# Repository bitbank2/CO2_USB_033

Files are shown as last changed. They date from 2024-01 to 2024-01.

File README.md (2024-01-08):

CO2_USB_033
===========
<b>What is it?</b><br>
A KiCad PCB project plus firmware for a portable CO2 sensor based on the WCH CH32X033 MCU. This is my first PCB with this chip and so far it's impressing me quite a bit. I was able to buy a small quantity for about 23 cents each. The 033 is part of the CH32X035 family and has a 48Mhz RISC-V core with 20K SRAM, 62K FLASH, USB full speed and many of the typical I/O capabilities of 32-bit MCUs. This project was more of an experiment to see if I could easily add some USB functionality to my battery powered CO2 sensor.<br><br>
<b>What's special about this project?</b><br>
By using a low cost display, MCU and sensor, my aim for this project was to make a practical and low cost way to carry a true CO2 sensor in your pocket. The CH32X033 also allowed me to easily add USB CDC support so that a PC could receive the sensor readings too. I use a clever single pushbutton circuit to control power and input. By using the enable pin of the 3.3v regulator in software control, the device can turn itself off. I use this feature to make sure the battery isn't accidentally left for dead. After 5 minutes of use, it will turn itself off.<br><br>
<b>Building the Project</b><br>
I used KiCad to design the PCB and all of the source files and Gerber zip is in the PCB folder ready to send for production. I assembled the board myself, so I don't have any assembly instructions/files with it. The firmware was built using MounRiver Studio IDE and the CH32X035 EVT provided on the WCH website.<br>

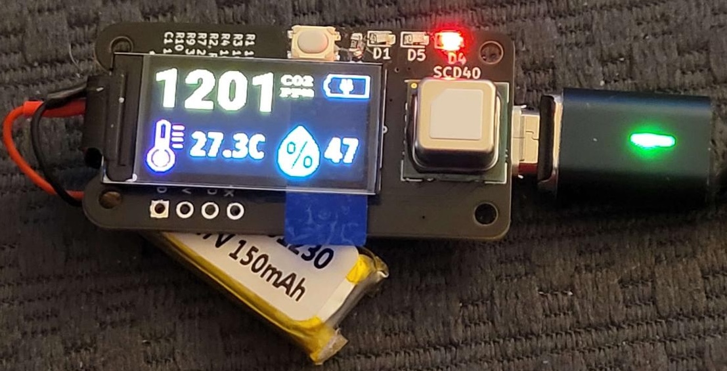
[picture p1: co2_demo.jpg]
CO2 Example use


If you find this code useful, please consider sending a donation or becoming a Github sponsor.



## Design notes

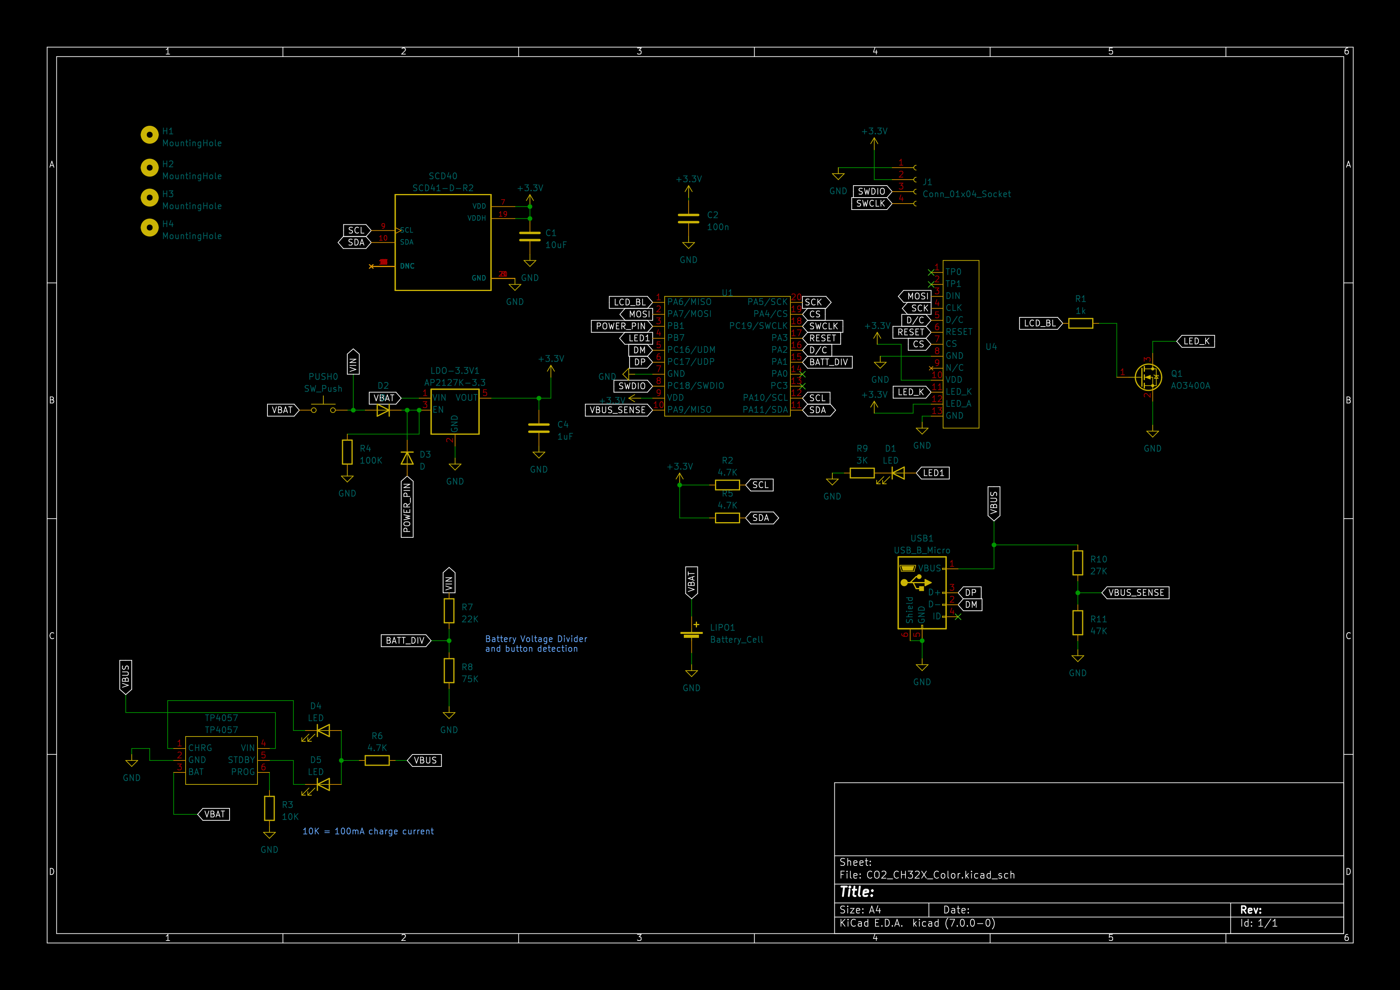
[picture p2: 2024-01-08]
PCB/schematic.png

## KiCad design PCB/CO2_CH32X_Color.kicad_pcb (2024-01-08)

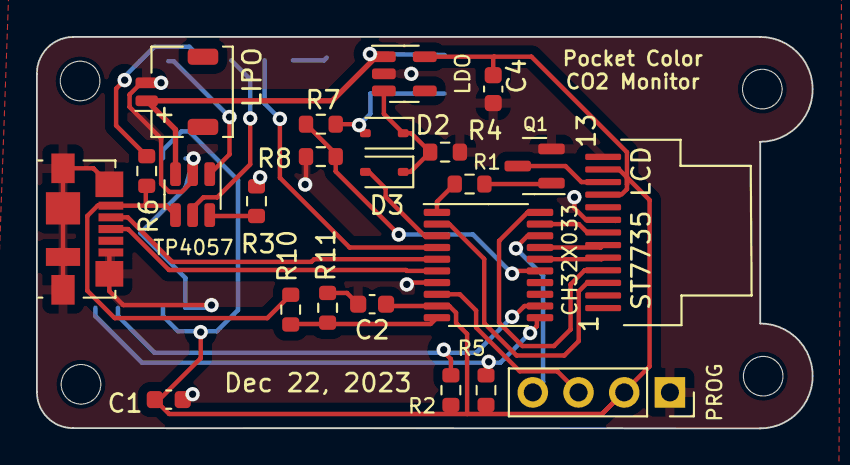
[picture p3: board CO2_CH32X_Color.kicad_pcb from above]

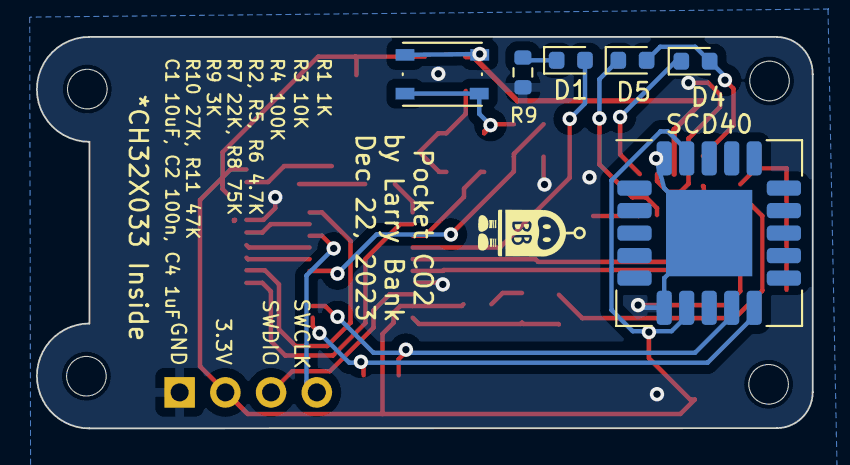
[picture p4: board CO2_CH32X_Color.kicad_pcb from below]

Board: 2 copper layers, 43.1 x 21.8 mm, 33 parts (6 on the bottom side), 29 nets.

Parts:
C1: 10uF; C_0603_1608Metric
C2: 100n; C_0603_1608Metric
C4: 1uF; C_0603_1608Metric
CH32X033: TSSOP-20_4.4x6.5mm_P0.65mm
D1, D4, D5: LED; LED_0603_1608Metric
D2, D3: D; D_SOD-323
H1, H2, H3, H4: MountingHole; MountingHole_2.2mm_M2_DIN965
LDO: AP2127K-3.3; SOT-23-5
LIPO: Battery_Cell; JST_SHL_SM02B-SHLS-TF_1x02-1MP_P1.00mm_Horizontal
PROG: Conn_01x04_Socket; PinSocket_1x04_P2.54mm_Vertical
PUSH0: SW_Push; SW_Push_1P1T_NO_Vertical_Wuerth_434133025816
Q1: AO3400A; SOT-23
R1: 1k; R_0603_1608Metric
R2, R5, R6: 4.7K; R_0603_1608Metric
R3: 10K; R_0603_1608Metric
R4: 100K; R_0603_1608Metric
R7: 22K; R_0603_1608Metric
R8: 75K; R_0603_1608Metric
R9: 3K; R_0603_1608Metric
R10: 27K; R_0603_1608Metric
R11: 47K; R_0603_1608Metric
SCD40: SCD41-D-R2; Sensirion_SCD4x-1EP_10.1x10.1mm_P1.25mm_EP4.8x4.8mm
TP4057: TP4057; SOT-23-6
U4: ST7735_13pin
USB1: USB_B_Micro; USB_Micro-B_Molex_47346-0001

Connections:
+3.3V: C1.1, C2.1, C4.1, CH32X033.9 (VDD), LDO.5 (VOUT), PROG.2, R2.1, R5.1, SCD40.7 (VDD), SCD40.19 (VDDH), U4.10 (VDD), U4.12 (LED_A)
BATT_DIV: CH32X033.15 (PA1), R7.1, R8.2
CS: CH32X033.19 (PA4/CS), U4.7 (CS)
DM: CH32X033.5 (PC16/UDM), USB1.2 (D-)
DP: CH32X033.6 (PC17/UDP), USB1.3 (D+)
D/C: CH32X033.16 (PA2), U4.5 (D/C)
GND: C1.2, C2.2, C4.2, CH32X033.7 (GND), LDO.2 (GND), LIPO.2 (-), PROG.1, Q1.2 (S), R3.2, R4.1, R8.1, R9.1, R11.1, SCD40.6 (GND), SCD40.20 (GND), SCD40.21 (GND), TP4057.2 (GND), U4.8 (GND), U4.13 (GND), USB1.5 (GND), USB1.6 (Shield)
LCD_BL: CH32X033.1 (PA6/MISO), R1.1
LED1: CH32X033.4 (PB7), D1.2 (A)
LED_K: Q1.3 (D), U4.11 (LED_K)
MOSI: CH32X033.2 (PA7/MOSI), U4.3 (DIN)
unnamed: D1.1 (K), R9.2
unnamed: D2.1 (K), D3.1 (K), LDO.3 (EN), R4.2
unnamed: D4.2 (A), D5.2 (A), R6.1
unnamed: D4.1 (K), TP4057.1 (CHRG)
unnamed: D5.1 (K), TP4057.5 (STDBY)
unnamed: Q1.1 (G), R1.2
unnamed: R3.1, TP4057.6 (PROG)
POWER_PIN: CH32X033.3 (PB1), D3.2 (A)
RESET: CH32X033.17 (PA3), U4.6 (RESET)
SCK: CH32X033.20 (PA5/SCK), U4.4 (CLK)
SCL: CH32X033.12 (PA10/SCL), R2.2, SCD40.9 (SCL)
SDA: CH32X033.11 (PA11/SDA), R5.2, SCD40.10 (SDA)
SWCLK: CH32X033.18 (PC19/SWCLK), PROG.4
SWDIO: CH32X033.8 (PC18/SWDIO), PROG.3
VBAT: LDO.1 (VIN), LIPO.1 (+), PUSH0.1, TP4057.3 (BAT)
VBUS: R6.2, R10.2, TP4057.4 (VIN), USB1.1 (VBUS)
VBUS_SENSE: CH32X033.10 (PA9/MISO), R10.1, R11.2
VIN: D2.2 (A), PUSH0.2, R7.2

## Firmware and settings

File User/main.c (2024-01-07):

//
// Pocket CO2 Sensor
// by Larry Bank (bitbank@pobox.com)
//
// Uses the CH32X033 TSSOP20 MCU
// Project started January 6, 2024
// Copyright (c) 2024 BitBank Software, Inc.
//
#include "debug.h"

#define CH32X035
#define BITBANG
#include <ch32x035_usbfs_device.h>
#include "../../libraries/ch32v_hal.inl"
#include "../../libraries/spi_lcd.inl"
#include "../../libraries/scd41.inl"
#include "Roboto_Black_40.h"
#include "Open_Sans_Condensed_Bold_24.h"
#include "battery.h"
#include "bb_logo_40x80.h"
#include "temp_bw.h"
#include "humidity.h"

#define LED_PIN 0xb7
#define POWER_PIN 0xb1
#define LCD_BL 0xa6
#define CS_PIN 0xa4
#define RST_PIN 0xa3
#define DC_PIN 0xa2
#define BATTBUTT_PIN 0xa1
#define VBUS_PIN 0xa9
#define SDA_PIN 0xab
#define SCL_PIN 0xaa

uint16_t usBG, usFG;
int iBattery, iBrightness;

void SetBrightness(uint8_t u8ccp)
{
    TIM_OCInitTypeDef TIM_OCInitStructure={0};

    TIM_OCInitStructure.TIM_OCMode = TIM_OCMode_PWM2;
    TIM_OCInitStructure.TIM_OutputState = TIM_OutputState_Enable;
    TIM_OCInitStructure.TIM_Pulse = u8ccp;
    TIM_OCInitStructure.TIM_OCPolarity = TIM_OCPolarity_High;
    TIM_OC1Init( TIM3, &TIM_OCInitStructure );
} /* SetBrightness() */

void SendUSBData(uint8_t *pData, int iLen)
{
    NVIC_DisableIRQ( USBFS_IRQn );
    NVIC_DisableIRQ( USBFS_IRQn );
    Uart.USB_Up_IngFlag = 0x01;
    Uart.USB_Up_TimeOut = 0x00;
    USBFS_Endp_DataUp( DEF_UEP3, pData, iLen, DEF_UEP_CPY_LOAD );
    NVIC_EnableIRQ( USBFS_IRQn );
} /* SendUSBData() */

void TIM3_PWMOut_Init(u16 arr, u16 psc, u16 ccp)
{
    uint8_t u8Pin;
    TIM_TimeBaseInitTypeDef TIM_TimeBaseInitStructure={0};

    RCC->APB2PCENR |= RCC_APB2Periph_GPIOA;
    RCC->APB1PCENR |= RCC_APB1Periph_TIM3;

    u8Pin = (LCD_BL & 0xf); // needed for backlight brightness
    GPIOA->CFGLR &= ~(0xf<<(4*u8Pin));
    GPIOA->CFGLR |= (GPIO_Speed_50MHz | GPIO_Mode_AF_PP)<<(4*u8Pin);

    TIM_TimeBaseInitStructure.TIM_Period = arr;
    TIM_TimeBaseInitStructure.TIM_Prescaler = psc;
    TIM_TimeBaseInitStructure.TIM_ClockDivision = TIM_CKD_DIV1;
    TIM_TimeBaseInitStructure.TIM_CounterMode = TIM_CounterMode_Up;
    TIM_TimeBaseInit( TIM3, &TIM_TimeBaseInitStructure);

    SetBrightness(ccp);
    TIM_CtrlPWMOutputs(TIM3, ENABLE );
    TIM_OC1PreloadConfig( TIM3, TIM_OCPreload_Disable );
    TIM_ARRPreloadConfig( TIM3, ENABLE );
    TIM_Cmd( TIM3, ENABLE );
} /* TIM3_PWMOut_Init() */

// Convert a number into a zero-terminated string
int i2str(char *pDest, int iVal)
{
        char *d = pDest;
        int i, iPlaceVal = 10000;
        int iDigits = 0;

        if (iVal < 0) {
                iDigits++;
                *d++ = '-';
                iVal = -iVal;
        }
        while (iPlaceVal) {
                if (iVal >= iPlaceVal) {
                        i = iVal / iPlaceVal;
                        *d++ = '0' + (char)i;
                        iVal -= (i*iPlaceVal);
                        iDigits++;
                } else if (iDigits != 0) {
                        *d++ = '0'; // non-zeros were already displayed
                }
                iPlaceVal /= 10;
        }
        if (d == pDest) // must be zero
                *d++ = '0';
        *d++ = 0; // terminator
        return (int)(d - pDest - 1); // string length
} /* i2str() */

void ShowLogo(void)
{
	uint16_t u16R, u16G;
	int i, j;
    lcdWriteString(56,16,"CH32X033", COLOR_RED, COLOR_BLACK, FONT_12x16);
    lcdWriteString(56,32,"Portable", COLOR_GREEN, COLOR_BLACK, FONT_12x16);
    lcdWriteString(40,56,"CO2 Sensor", COLOR_BLUE, COLOR_BLACK, FONT_12x16);
    for (int j=0; j<2; j++) { // iterations
        u16G = 63; u16R = 0; // start at pure green
    	for (i=0; i<32; i++) { // G -> Y
    		lcdDrawPattern((uint8_t *)bb_logo_40x80, 8, 0, 0, 40, 80, 0, 7 | (u16R<<11) | (u16G<<5));
    		u16R++;
        	Delay_Ms(25);
    	} // for i
    	u16R = 31;
    	for (i=0; i<32; i++) { // Y -> R
    		lcdDrawPattern((uint8_t *)bb_logo_40x80, 8, 0, 0, 40, 80, 0, 7 | (u16R<<11) | (u16G<<5));
    		u16G-=2;
        	Delay_Ms(25);
    	} // for i
    	u16G = 1;
    	for (i=0; i<32; i++) { // R -> Y
    		lcdDrawPattern((uint8_t *)bb_logo_40x80, 8, 0, 0, 40, 80, 0, 7 | (u16R<<11) | (u16G<<5));
    		u16G+=2;
        	Delay_Ms(25);
    	} // for i
    	u16G = 63;
    	for (i=0; i<32; i++) { // Y -> G
    		lcdDrawPattern((uint8_t *)bb_logo_40x80, 8, 0, 0, 40, 80, 0, 7 | (u16R<<11) | (u16G<<5));
    		u16R--;
        	Delay_Ms(25);
    	} // for i
    } // for j

} /* ShowLogo() */

void PowerDown(void)
{
	lcdFill(0);
	lcdWriteString(8,0,"Powering Off", COLOR_RED, 0, FONT_12x16);
	lcdWriteString(14,32,"Release the", 0xfe40, 0, FONT_12x16);
	lcdWriteString(14,48,"button when", 0xfe40, 0, FONT_12x16);
	lcdWriteString(32,64,"ready...", 0xfe40, 0, FONT_12x16);
	digitalWrite(POWER_PIN, 0); // shut off power to LDO
	while (1) {};
} /* PowerDown() */

void ShowCO2(void)
{
	int i, x, iColor;
	char szTemp[32];
	uint8_t *s;
	uint32_t rem;
	static int iOldLen = 0;
    const uint16_t usColors[7] = {0x7e0, 0x67e0, 0xffe0, 0xfe40, 0xfbc0, 0xf800, 0xffff};

    if (digitalRead(VBUS_PIN) == 1) {
    	// connected to PC; send sensor data report over USB
    	sprintf(szTemp, "%d,%d.%d,%d\n\r", _iCO2, _iTemperature/10, _iTemperature % 10, _iHumidity/10);
    	SendUSBData(szTemp, strlen(szTemp));
    	Delay_Ms(100);
    }
    i = i2str(szTemp, (int)_iCO2);
    if (i != iOldLen) { // if the number of digits of CO2 changes, repaint everything
        lcdFill(usBG);
        iOldLen = i;
    }
    i = _iCO2 - 500;
    if (i < 0) i = 0;
    iColor = udivmod32(i, 250, NULL);
    if (iColor > 5) iColor = 5; // show with a color
    lcdWriteStringCustom(&Roboto_Black_40, 0, 30, szTemp, usColors[iColor], usBG, 1);
    x = lcdGetCursorX();
    lcdWriteString(x, 2, "CO2", usColors[iColor], usBG, FONT_8x8);
    lcdWriteString(x, 10, "ppm", usColors[iColor], usBG, FONT_8x8);

	lcdDrawPattern((uint8_t *)&temp_bw[0x92], 4, 0, 40, 26, 40, 0, COLOR_MAGENTA);
    lcdDrawPattern((uint8_t *)&humidity[0x92], 4, 96, 39, 32, 41, 0, COLOR_CYAN);
    i = _iTemperature/10;
    rem = _iTemperature % 10;
    i2str(szTemp, i); // whole part
    szTemp[2] = '.';
    szTemp[3] = '0' + rem; // fraction
    szTemp[4] = 'C';
    szTemp[5] = 0;
//    lcdWriteString(32, 52, szTemp, usFG, usBG, FONT_12x16);
    lcdWriteStringCustom(&Open_Sans_Condensed_Bold_24, 32, 66, szTemp, COLOR_WHITE, usBG, 1);
    i2str(szTemp, _iHumidity/10); // throw away fraction since it's not accurate
//    lcdWriteString(132, 52, szTemp, usFG, usBG, FONT_12x16);
    lcdWriteStringCustom(&Open_Sans_Condensed_Bold_24, 132, 66, szTemp, COLOR_WHITE, usBG, 1);
    // show battery level
	if (digitalRead(VBUS_PIN) == 1|| (iBattery > 3000 && iBattery <4096)) { // valid values, otherwise no battery measurement
		   if (digitalRead(VBUS_PIN) == 1) {
			   s = (uint8_t *)battchg_32x16; // charging
			   iColor = 6; // white
		   } else if (iBattery <= 3220) {
				s = (uint8_t *)batt0_32x16; // <= 3.4v
				iColor = 5; // red
			} else if (iBattery <= 3407) {
				s = (uint8_t *)batt0_32x16; // <= 3.6v
				iColor = 4;
			} else if (iBattery < 3609) {
				s = (uint8_t *)batt25_32x16; // <= 3.8v
				iColor = 3;
			} else if (iBattery < 3711) {
				s = (uint8_t *)batt50_32x16; // <= 3.9v
				iColor = 2;
			} else if (iBattery < 3795) {
				s = (uint8_t *)batt75_32x16; // <= 4.0v
				iColor = 1;
			} else {
				s = (uint8_t *)batt100_32x16;
				iColor = 0;
			}
			lcdDrawPattern(s, 4, 128, 0, 32, 16, 0, usColors[iColor]);
	}
} /* ShowCO2() */

void ShowCountdown(int iSecs)
{
uint32_t i, rem;
char szTemp[8];

    szTemp[0] = '0';
    i = udivmod32(iSecs, 60, &rem);
    szTemp[1] = i +'0';
    szTemp[2] = ':';
    szTemp[3] = udivmod32(rem, 10, &rem) + '0';
    szTemp[4] = rem + '0';
    szTemp[5] = 0;
    lcdWriteStringCustom(&Roboto_Black_40, 10, 56, szTemp, usFG, usBG, 1);
} /* ShowCountdown() */

void RunCalibrate(void)
{
int i;

    lcdFill(usBG);
    lcdWriteString(2,2,"Calibrating..", usFG, usBG, FONT_12x16);
//    while (GetButtons() != 0) {};
//   scd41_start(SCD_POWERMODE_NORMAL);
   // allow 3 minutes of normal collection
   for (i=210; i>=0; i--) {
      ShowCountdown(i);
//      j = GetButtons();
//      if (j == 3) { // user quit
//              scd41_stop();
//              return;
//      }
      Delay_Ms(1000);
   }
   scd41_stop(); // stop periodic measurement
   i = scd41_recalibrate(423); // force recalibration
   lcdWriteString(2,32, (i == SCD_SUCCESS) ? "Success!":"Failed", (i == SCD_SUCCESS) ? COLOR_GREEN:COLOR_RED, usBG, FONT_12x16);
   lcdWriteString(0,72, "Press button to exit", usFG, usBG, FONT_8x8);
   i = 0;
   while (digitalRead(BATTBUTT_PIN) == 0 && i < 3000) {
         Delay_Ms(20);
         i++;
   }
   if (i >= 3000) { // user left it sitting there, turn off
	   PowerDown();
   }
   scd41_start(SCD_POWERMODE_NORMAL); // restart the sensor
   lcdFill(usBG);
} /* RunCalibrate() */

void RunLowPower(void)
{
	int iTick, iHold, iShutdown;

	scd41_stop();
	scd41_start(SCD_POWERMODE_LOW); // switch to low pwoer mode
	SetBrightness(254); // turn off backlight
	iTick = iHold = 0;
	iShutdown = 120*60*8; // auto shutdown after 2 hours
	while (1) {
		if (digitalRead(BATTBUTT_PIN)) { // user pressed the button
			iHold++;
			if (iHold >= 8) { // exit mode
				SetBrightness(iBrightness);
				scd41_stop();
				scd41_start(SCD_POWERMODE_NORMAL);
				return;
			}
		} else if (iHold) { // press+release, show stats
			iHold = 0;
    		scd41_getSample();
    		SetBrightness(iBrightness);
    		ShowCO2(); // display the current conditions on the OLED
    		Delay_Ms(1500);
    		SetBrightness(254);
		}
		iTick++;
		iShutdown--;
		if (iShutdown == 0) {
			PowerDown(); // automatically shut off after 2 hours
		}
	} // while !bDone
} /* RunLowPower() */
void ADCInit(void)
{
    ADC_InitTypeDef  ADC_InitStructure = {0};
    GPIO_InitTypeDef GPIO_InitStructure = {0};

    RCC_APB2PeriphClockCmd(RCC_APB2Periph_GPIOA, ENABLE);
    RCC_APB2PeriphClockCmd(RCC_APB2Periph_ADC1, ENABLE);
    //RCC_ADCCLKConfig(RCC_PCLK2_Div8);
    ADC_CLKConfig(ADC1, ADC_CLK_Div8);

    GPIO_InitStructure.GPIO_Pin = GPIO_Pin_1; // A1
    GPIO_InitStructure.GPIO_Mode = GPIO_Mode_AIN;
    GPIO_Init(GPIOA, &GPIO_InitStructure);

    ADC_DeInit(ADC1);
    ADC_InitStructure.ADC_Mode = ADC_Mode_Independent;
    ADC_InitStructure.ADC_ScanConvMode = DISABLE;
    ADC_InitStructure.ADC_ContinuousConvMode = ENABLE;
    ADC_InitStructure.ADC_ExternalTrigConv = ADC_ExternalTrigInjecConv_None;
    ADC_InitStructure.ADC_DataAlign = ADC_DataAlign_Right;
    //ADC_InitStructure.ADC_NbrOfChannel = 1;
    ADC_Init(ADC1, &ADC_InitStructure);

//    ADC_InjectedChannelConfig(ADC1, ADC_Channel_7, 1, ADC_SampleTime_241Cycles);
    ADC_RegularChannelConfig(ADC1, ADC_Channel_1, 1, ADC_SampleTime_11Cycles);
 //   ADC_Calibration_Vol(ADC1, ADC_CALVOL_75PERCENT);
//    ADC_ITConfig(ADC1, ADC_IT_AWD, ENABLE);
//    ADC_AutoInjectedConvCmd(ADC1, ENABLE);
    ADC_Cmd(ADC1, ENABLE);

//    ADC_ResetCalibration(ADC1);
//    while(ADC_GetResetCalibrationStatus(ADC1));
 //   ADC_StartCalibration(ADC1);
 //   while(ADC_GetCalibrationStatus(ADC1));

} /* ADCInit() */

uint16_t ADCGetValue(void)
{
    uint16_t val;

    ADC_SoftwareStartConvCmd(ADC1, ENABLE);
//    Delay_Ms(100);
//    while(!ADC_GetFlagStatus(ADC1, ADC_FLAG_EOC));

    val = ADC_GetConversionValue(ADC1);
    //val = ADC_GetInjectedConversionValue(ADC1, ADC_InjectedChannel_1);
    return val;
} /* ADCGetValue() */

void RunMenu(void)
{
	int iItem = 0, bDone = 0;
	int iTick, iTimeout;
	const char *szMenuItem[] = {"Calibrate", "Low Power", "Power Off", "Exit Menu"};

menu_start:
	lcdFill(0);
	lcdWriteString(14,0,"Option Menu", COLOR_CYAN, 0, FONT_12x16);
	lcdWriteString(20,64,"Press to change", COLOR_YELLOW, 0, FONT_8x8);
	lcdWriteString(0,72,"Press+hold to select", COLOR_YELLOW, 0, FONT_8x8);
	iTick = iTimeout = 0;
	lcdWriteString(26,32,szMenuItem[iItem], COLOR_WHITE, 0, FONT_12x16);
	while (!bDone) {
		if (digitalRead(BATTBUTT_PIN)) {
			lcdWriteString(26,32,szMenuItem[iItem], COLOR_WHITE, 0, FONT_12x16); // flash menu item when changing
			iTick++;
			iTimeout = 0;
			if (iTick >= 8) {
				for (iTick = 0; iTick < 3; iTick++) {
					lcdWriteString(26,32,szMenuItem[iItem], COLOR_WHITE, 0, FONT_12x16); // flash menu item when changing
					Delay_Ms(250);
					lcdWriteString(26,32,szMenuItem[iItem], COLOR_WHITE, COLOR_BLUE, FONT_12x16);
					Delay_Ms(250);
				}
				switch (iItem) {
				case 0: // calibrate
					RunCalibrate();
				    scd41_start(SCD_POWERMODE_NORMAL); // start in normal mode again
				    goto menu_start;
					break;
				case 1: // low power
					RunLowPower();
					goto menu_start;
					break;
				case 2: // Power Off
					PowerDown();
					break;
				case 3: // exit
					bDone = 1;
					lcdFill(0);
		    		while (digitalRead(BATTBUTT_PIN) == 1) {}; // wait for user to release button from menu selection
					ShowCO2();
					break;
				} // switch
			} // long press
		} else { // button release
			if (iTick) { // button was pressed and released
				iTick = 0;
				iItem++;
				if (iItem >= 4) iItem = 0;
				lcdWriteString(26,32,szMenuItem[iItem], COLOR_WHITE, 0, FONT_12x16); // show new item
			}
		}
		iTimeout++;
        if (iTimeout > 8*60) {
        	// The user forgot about us for > 1 minute, turn ourselves off
        	digitalWrite(POWER_PIN, 0);
        }
		Delay_Ms(156);
	} // while !bDone
} /* RunMenu() */

int main(void)
{
    int i, iHold, iShutdown, iTick;
    int iOrientation = 0;
    uint8_t ucTemp[32];

    NVIC_PriorityGroupConfig(NVIC_PriorityGroup_2);
    SystemCoreClockUpdate();
    SetClock(48000000); // DEBUG
    Delay_Init();
    ADCInit();
    iBattery = 0;
    iTick = 0;
    while (iBattery < 800 && iTick < 100) { // wait for a valid read
    	iBattery = ADCGetValue(); // get battery voltage at startup
    	iTick++;
    	Delay_Ms(1); // it takes a few ms for the value to rise to it's true amount
    }
	ADC_DeInit(ADC1);
    pinMode(BATTBUTT_PIN, INPUT);

    pinMode(LED_PIN, OUTPUT);
    pinMode(POWER_PIN, OUTPUT);
    pinMode(VBUS_PIN, INPUT_PULLDOWN);
    digitalWrite(POWER_PIN, 1);
    I2CInit(SDA_PIN, SCL_PIN, 100000);
    iBrightness = 230;
    TIM3_PWMOut_Init( 255, 512, iBrightness ); // start a 20% duty cycle PWM output on D4 of about 512hz

    if (digitalRead(VBUS_PIN) == 1) {
    	// Start USB CDC service and send serial reports of the sensor readings
    	RCC_Configuration();
    	USBFS_RCC_Init();
    	USBFS_Device_Init( ENABLE, PWR_VDD_SupplyVoltage());
    } // connected to USB bus

//    pinMode(LCD_BL, OUTPUT);
//	digitalWrite(LCD_BL, 1);
//    lcdSetDMA(0); // Disable DMA since it conflicts with USB's use
    lcdInit(LCD_ST7735S_80x160, 24000000, CS_PIN, DC_PIN, RST_PIN, 0/*BL_PIN*/, 0, 0);
    lcdWriteCMD(0x21); // inverted
    lcdWriteCMD(0x36);
    ucTemp[0] = 0x68; // swap r/b
    lcdWriteDATA(ucTemp, 1);
    usBG = 0; usFG = 0xffff;
//    lcdOrientation(iOrientation);
    lcdFill(usBG);
    ShowLogo();
 //   if (I2CTest(0x62)) {
 //   	lcdWriteString(0,0,"Found SCD41!", COLOR_GREEN, COLOR_BLACK, FONT_12x16);
 //   } else {
 //   	lcdWriteString(0,0,"SCD41 not found", COLOR_RED, COLOR_BLACK, FONT_12x16);
//    }
//    Delay_Ms(10000);
    scd41_setAutoCalibration(0); // make sure auto calibration is turned off
    scd41_start(SCD_POWERMODE_NORMAL);
    iTick = -1;
    iHold = 0;
    iShutdown = 5*60*8; // auto shutdown after 5 minutes
    while(1)
    {
    	Delay_Ms(156);
    	iTick++;
    	if ((iTick & 31) == 0) { // show new sample every 5 seconds
            scd41_getSample();
            ShowCO2();
    	}
    	iShutdown--;
    	if (iShutdown == 0) {
    		if (digitalRead(VBUS_PIN) == 1) {
    			// we're plugged in, no need to shut down
    			iShutdown = 5*60*8; // reset the shutdown timer to 5 minutes
    			continue;
    		}
    		PowerDown(); // time ran out, turn off the power
    	}
    	if (digitalRead(BATTBUTT_PIN) == 1) {
    		iHold++; // hold for 1.25 seconds to shut down
    		if (iHold >= 8) {
    			PowerDown();
    		}
    	} else if (iHold) {
    		iHold = 0; // reset hold timer
    		RunMenu();
    	}
    } // while (1)
} /* main() */

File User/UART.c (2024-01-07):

/********************************** (C) COPYRIGHT *******************************
* File Name          : UART.C
* Author             : WCH
* Version            : V1.01
* Date               : 2023/04/06
* Description        : uart serial port related initialization and processing
*******************************************************************************
* Copyright (c) 2021 Nanjing Qinheng Microelectronics Co., Ltd.
* Attention: This software (modified or not) and binary are used for 
* microcontroller manufactured by Nanjing Qinheng Microelectronics.
*******************************************************************************/

#include "UART.h"

/*******************************************************************************/
/* Variable Definition */
/* Global */

/* The following are serial port transmit and receive related variables and buffers */
volatile UART_CTL Uart;

__attribute__ ((aligned(4))) uint8_t  UART2_Tx_Buf[ DEF_UARTx_TX_BUF_LEN ];  /* Serial port 2 transmit data buffer */
__attribute__ ((aligned(4))) uint8_t  UART2_Rx_Buf[ DEF_UARTx_RX_BUF_LEN ];  /* Serial port 2 receive data buffer */
volatile uint32_t UARTx_Rx_DMACurCount;                       /* Serial port 1 receive dma current counter */
volatile uint32_t UARTx_Rx_DMALastCount;                      /* Serial port 1 receive dma last value counter  */

/*********************************************************************
 * @fn      RCC_Configuration
 *
 * @brief   Configures the different system clocks.
 *
 * @return  none
 */
uint8_t RCC_Configuration( void )
{
    RCC_APB2PeriphClockCmd( RCC_APB2Periph_GPIOA, ENABLE );
//    RCC_APB1PeriphClockCmd( RCC_APB1Periph_USART2, ENABLE );
//    RCC_APB1PeriphClockCmd( RCC_APB1Periph_TIM3, ENABLE );
    RCC_AHBPeriphClockCmd( RCC_AHBPeriph_DMA1, ENABLE );
    return 0;
}

/*********************************************************************
 * @fn      TIM3_Init
 *
 * @brief   100us Timer
 *          144 * 100 * 13.8888 -----> 100uS
 *
 * @return  none
 */
void TIM3_Init( void )
{
    TIM_TimeBaseInitTypeDef  TIM_TimeBaseStructure = {0};

    TIM_DeInit( TIM3 );

    /* Time base configuration */
    TIM_TimeBaseStructure.TIM_Period = 100 - 1;
    TIM_TimeBaseStructure.TIM_Prescaler = SystemCoreClock / 1000000 - 1;
    TIM_TimeBaseStructure.TIM_ClockDivision = 0;
    TIM_TimeBaseStructure.TIM_CounterMode = TIM_CounterMode_Up;
    TIM_TimeBaseInit( TIM3, &TIM_TimeBaseStructure );

    /* Clear TIM3 update pending flag */
    TIM_ClearFlag( TIM3, TIM_FLAG_Update );

    /* TIM IT enable */
    TIM_ITConfig( TIM3, TIM_IT_Update, ENABLE );

    /* Enable Interrupt */
    NVIC_EnableIRQ( TIM3_IRQn );

    /* TIM3 enable counter */
    TIM_Cmd( TIM3, ENABLE );
}

/*********************************************************************
 * @fn      UART2_CfgInit
 *
 * @brief   Uart2 configuration initialization
 *
 * @return  none
 */
void UART2_CfgInit( uint32_t baudrate, uint8_t stopbits, uint8_t parity )
{
    USART_InitTypeDef USART_InitStructure = {0};
    GPIO_InitTypeDef  GPIO_InitStructure = {0};
    uint16_t dat = dat;

    /* delete contains in ( ... )  */
    /* First set the serial port introduction to output high then close the TE and RE of CTLR1 register (note that USARTx->CTLR1 register setting 9 bits has a limit) */
    /* Note: This operation must be performed, the TX pin otherwise the level will be pulled low */
    GPIO_SetBits( GPIOA, GPIO_Pin_2 );
    GPIO_InitStructure.GPIO_Pin   = GPIO_Pin_2;
    GPIO_InitStructure.GPIO_Speed = GPIO_Speed_50MHz;
    GPIO_InitStructure.GPIO_Mode  = GPIO_Mode_Out_PP;
    GPIO_Init( GPIOA, &GPIO_InitStructure );

    /* clear te/re */
    USART2->CTLR1 &= ~( USART_CTLR1_TE | USART_CTLR1_RE );

    /* USART2 Hard configured: */
    /* Configure USART1 Rx (PA3) as input floating */
    GPIO_InitStructure.GPIO_Pin   = GPIO_Pin_3;
    GPIO_InitStructure.GPIO_Mode  = GPIO_Mode_IPU;
    GPIO_Init( GPIOA, &GPIO_InitStructure );

    /* Configure USART2 Tx (PA2) as alternate function push-pull */
    GPIO_InitStructure.GPIO_Pin   = GPIO_Pin_2;
    GPIO_InitStructure.GPIO_Speed = GPIO_Speed_50MHz;
    GPIO_InitStructure.GPIO_Mode  = GPIO_Mode_AF_PP;
    GPIO_Init( GPIOA, &GPIO_InitStructure );

    /* Test IO */
    GPIO_InitStructure.GPIO_Pin   = GPIO_Pin_15;
    GPIO_InitStructure.GPIO_Speed = GPIO_Speed_50MHz;
    GPIO_InitStructure.GPIO_Mode  = GPIO_Mode_Out_PP;
    GPIO_Init( GPIOA, &GPIO_InitStructure );

    /* USART2 configured as follow:
        - BaudRate = 115200 baud  
        - Word Length = 8 Bits
        - One Stop Bit
        - No parity
        - Hardware flow control disabled (RTS and CTS signals)
        - Receive and transmit enabled
        - USART Clock disabled
        - USART CPOL: Clock is active low
        - USART CPHA: Data is captured on the middle 
        - USART LastBit: The clock pulse of the last data bit is not output to 
                         the SCLK pin
    */
    USART_InitStructure.USART_BaudRate = baudrate;
    USART_InitStructure.USART_WordLength = USART_WordLength_8b;

    /* Number of stop bits (0: 1 stop bit; 1: 1.5 stop bits; 2: 2 stop bits). */
    if( stopbits == 1 )
    {
        USART_InitStructure.USART_StopBits = USART_StopBits_1_5;
    }
    else if( stopbits == 2 )
    {
        USART_InitStructure.USART_StopBits = USART_StopBits_2;
    }
    else
    {
        USART_InitStructure.USART_StopBits = USART_StopBits_1;
    }

    /* Check digit (0: None; 1: Odd; 2: Even; 3: Mark; 4: Space); */
    if( parity == 1 )
    {
        USART_InitStructure.USART_Parity = USART_Parity_Odd;
        USART_InitStructure.USART_WordLength = USART_WordLength_9b;
    }
    else if( parity == 2 )
    {
        USART_InitStructure.USART_Parity = USART_Parity_Even;
        USART_InitStructure.USART_WordLength = USART_WordLength_9b;
    }
    else
    {
        USART_InitStructure.USART_Parity = USART_Parity_No;
    }
    USART_InitStructure.USART_HardwareFlowControl = USART_HardwareFlowControl_None;
    USART_InitStructure.USART_Mode = USART_Mode_Rx | USART_Mode_Tx;
    USART_Init( USART2, &USART_InitStructure );
    USART_ClearFlag( USART2, USART_FLAG_TC );

    /* Enable USART2 */
    USART_Cmd( USART2, ENABLE );
}
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

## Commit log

2024-01-07 First version working with sensor values going to CDC serial
2024-01-08 Added KiCad files
    [CO2_CH32X_Color.kicad_pcb, CO2_CH32X_Color.kicad_sch]
